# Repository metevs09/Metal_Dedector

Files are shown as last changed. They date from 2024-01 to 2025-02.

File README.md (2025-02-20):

# Metal Detector Project

This project provides a comprehensive reference for building a pulse induction metal detector. It includes the general system scheme, hardware design files, PCB designs, CAM files for manufacturing, and a USB to UART module for ESP32 integration.

Metal Detector

## Overview
The Metal Detector project is designed to help enthusiasts and professionals understand and implement a pulse induction metal detector. The repository contains:

- General Scheme: Detailed system and hardware schematics.
- PCB Design Files: Ready-to-use designs for fabricating the circuit board.
- CAM Files: Files required for computer-aided manufacturing.
- ESP32 Integration: A USB to UART module for connecting the detector to an ESP32 microcontroller.
## Features
- Pulse Induction Operation: Implements the principles of pulse induction metal detection.
- Detailed Schematics: Complete general and hardware design documents.
- PCB and CAM Files: Design files for PCB manufacturing and assembly.
- ESP32 Interface: Provides a USB to UART bridge for interfacing with ESP32-based systems.
  
## Repository Structure
```
Metal_Dedector/
- ├── CAM file/              # CAM files for PCB manufacturing
- ├── PCB files/             # PCB design files and layouts
- ├── USB to UART for ESP32/  # Interface files for ESP32 integration
- ├── Metal Dedektör.drawio   # Schematic diagram created with draw.io
- ├── README.md              # This README file
- └── SECURITY.md            # Security policy information
```
## Getting Started

### Prerequisites

#### Electronics Knowledge:
- Basic understanding of electronics and PCB design.
#### Software Tools:
- Draw.io for viewing and editing schematics.
- PCB design software (such as Eagle or KiCad) for viewing the PCB files.
- A computer with a USB interface for using the ESP32 integration module.
### Installation
#### Clone the Repository:
```git clone https://github.com/metevs09/Metal_Dedector.git```

#### Review the Design Files:
- Open Metal Dedektör.drawio with Draw.io to view the schematic.
- Check the PCB files in the PCB files/ directory.
- Refer to the files in USB to UART for ESP32/ for ESP32 interfacing details.
#### Manufacture and Assemble:
- Use the CAM files to prepare your PCB for manufacturing.
- Assemble the components following standard electronic assembly practices.
### Usage
Once the hardware is assembled:

1. Connect the ESP32 via the USB to UART interface.
2. Use your preferred development environment to load and run firmware.
3. Test the metal detector according to the provided schematic and design guidelines.
> Note: Always follow proper safety procedures when working with electronic circuits and during the assembly process.

License
This project is licensed under the MIT License. See the LICENSE file for more details.

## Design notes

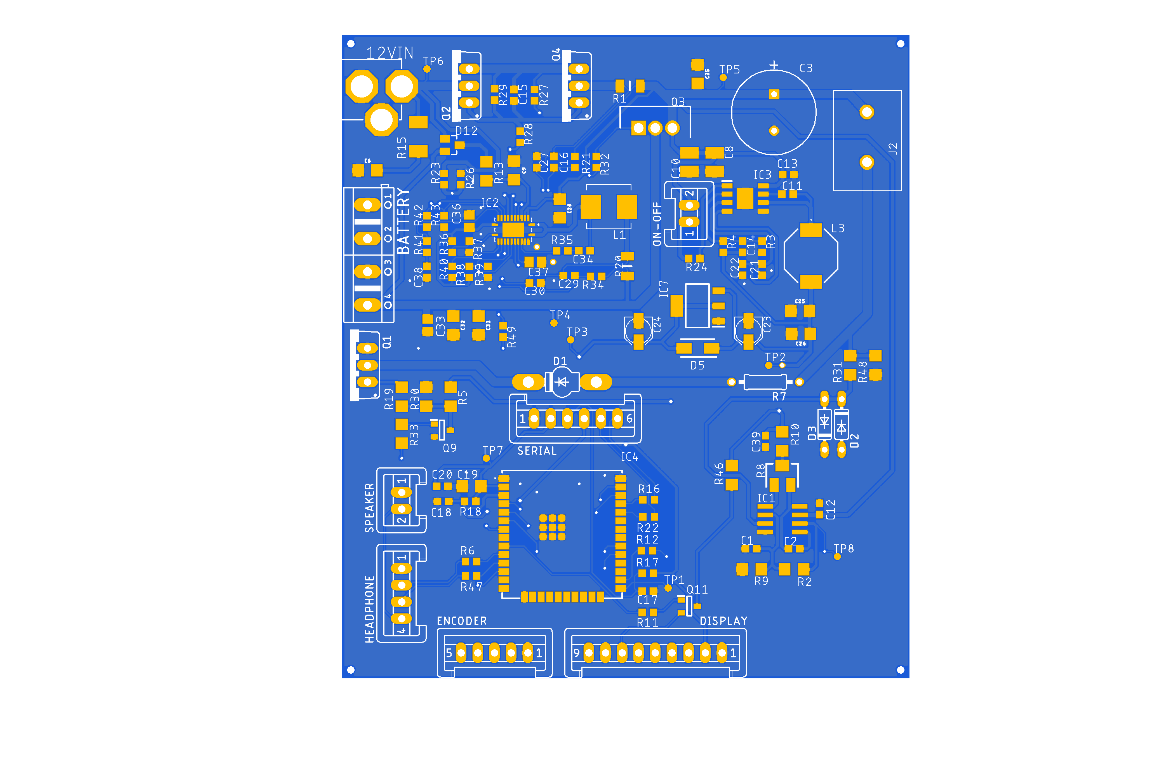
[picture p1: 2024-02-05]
CAM file/Metal Detector.png

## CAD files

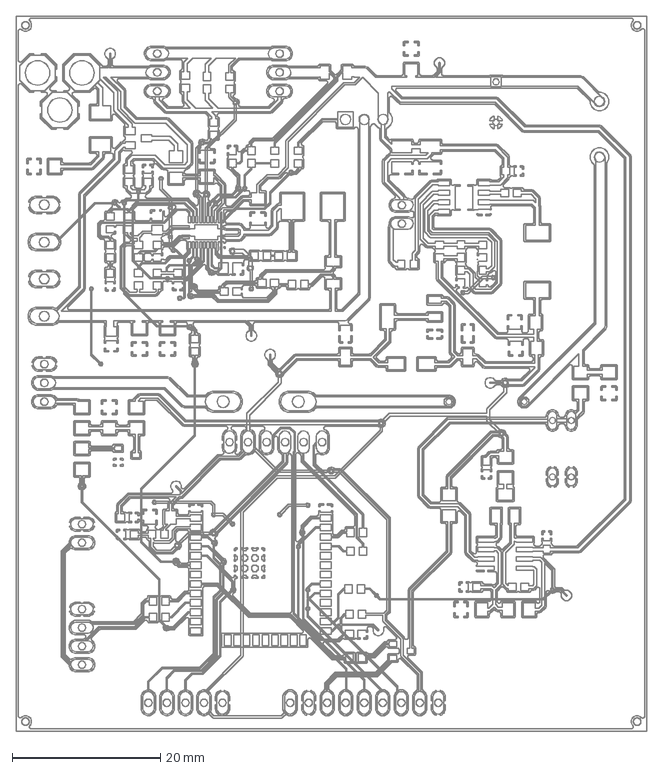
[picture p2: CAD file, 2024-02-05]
CAM file/Metal Detector.dxf
85.1 x 96.5 mm

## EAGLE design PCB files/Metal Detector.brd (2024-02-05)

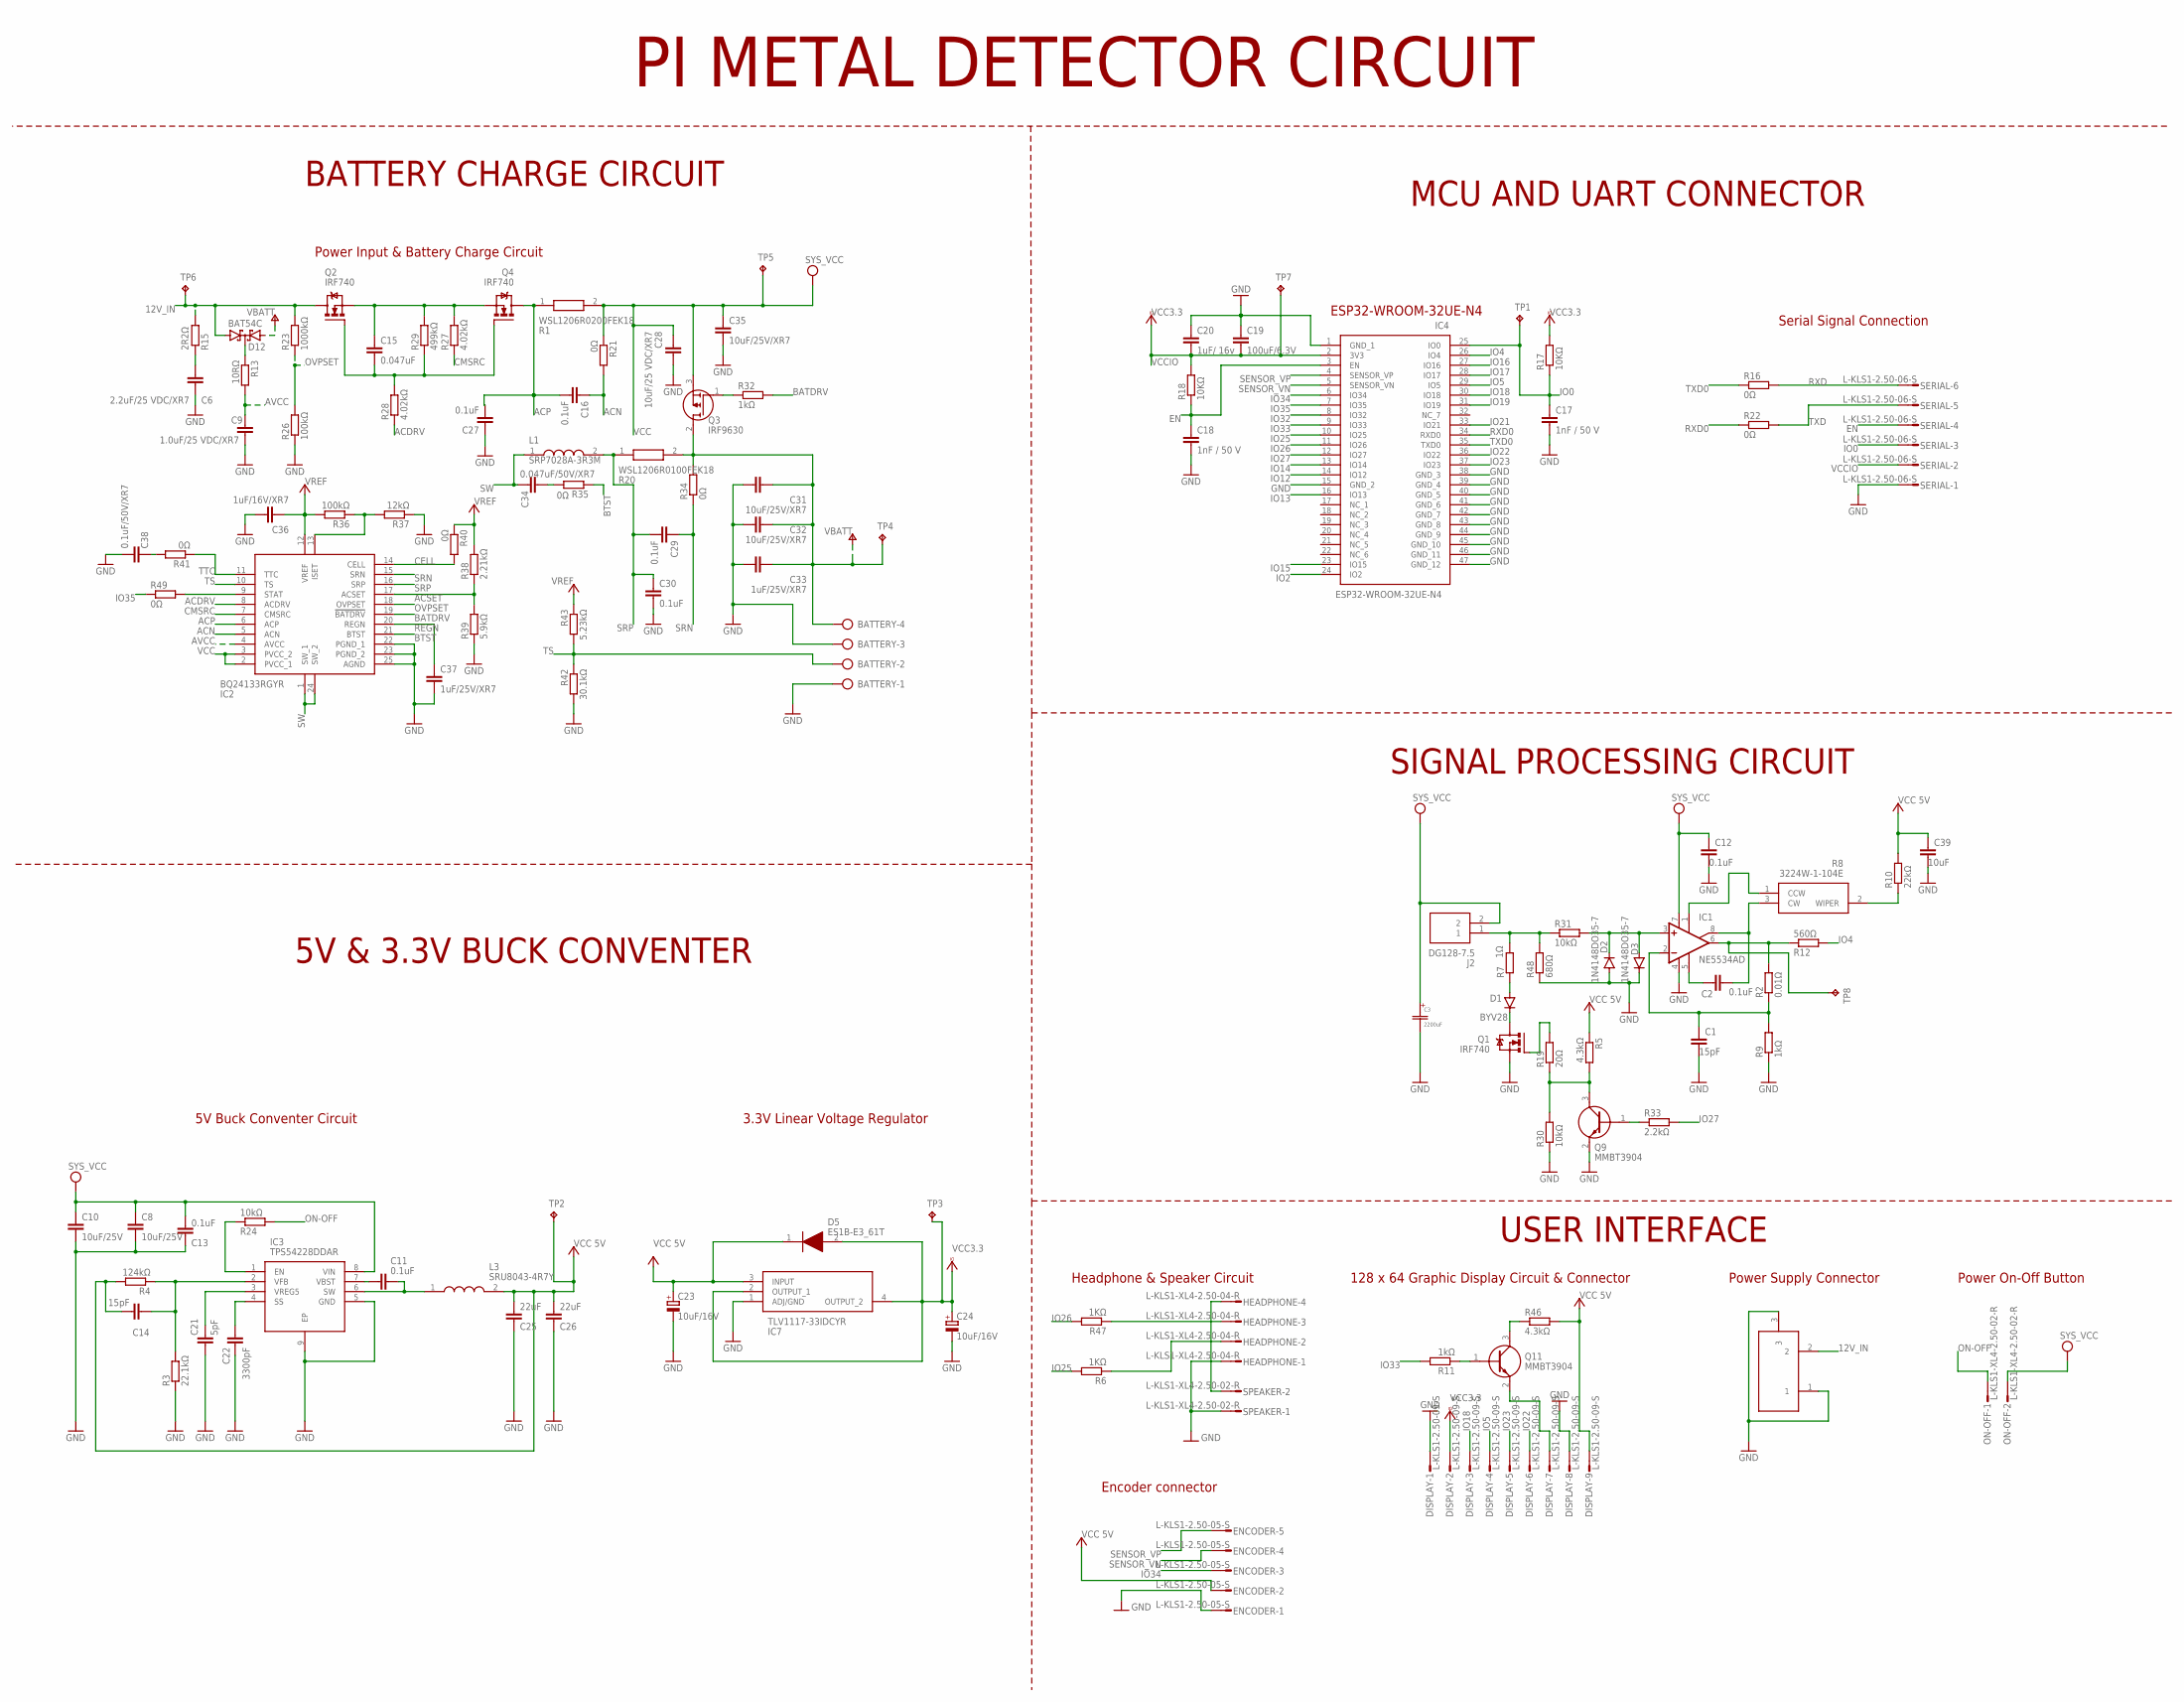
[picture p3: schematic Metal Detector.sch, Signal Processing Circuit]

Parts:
12VIN: DC21MMX; DC-21MM
BATTERY: AK500/4
C1, C14: 15pF; C0603
C2, C11, C12, C13, C16, C27, C29, C30: 0.1uF; C0603
C3: 2200uF; CAP_12.5_X_20_PAN
C6: 2.2uF/25 VDC/XR7; 1206
C8, C10: 10uF/25V; C1210
C9: 1.0uF/25 VDC/XR7; 1206
C15: 0.047uF; C0603
C17, C18: 1nF / 50 V; C0603
C19: 100uF/6.3V; C1206
C20: 1uF/ 16v; C0603
C21: 5pF; C0603
C22: 3300pF; C0603
C23, C24: 10uF/16V; PANASONIC_B
C25, C26: 22uF; 1206
C28: 10uF/25 VDC/XR7; 1206
C31, C32, C35: 10uF/25V/XR7; 1206
C33, C37: 1uF/25V/XR7; C0805
C34: 0.047uF/50V/XR7; C0603
C36: 1uF/16V/XR7; C0805
C38: 0.1uF/50V/XR7; C0603
C39: 10uF; C0603
D1: BYV28; SOD64-10
D2, D3: 1N4148DO35-7; DO35-7
D5: ES1B-E3_61T; DIOM5127X229N
D12: BAT54C; SOT23
DISPLAY: L-KLS1-2.50-09-S; S09P
ENCODER: L-KLS1-2.50-05-S; S05P
HEADPHONE: L-KLS1-XL4-2.50-04-R; S04P
IC1: NE5534AD; SO08
IC2: BQ24133RGYR
IC3: TPS54228DDAR; SOIC127P600X170-9N
IC4: ESP32-WROOM-32UE-N4; ESP32WROOM32UEN4
IC7: TLV1117-33IDCYR; SOT230P700X180-4N
J2: DG128-7.5; DG1287502P1400AH
L1: SRP7028A-3R3M; SRP7028A3R3M
L3: SRU8043-4R7Y; SRU8043330Y
ON-OFF: L-KLS1-XL4-2.50-02-R; S02P
Q1, Q2, Q4: IRF740; TO220BV
Q3: IRF9630; TO254P465X1024X2050-3P
Q9, Q11: MMBT3904; SOT95P240X120-3N
R1: WSL1206R0200FEK18; RESC3216X89N
R2: 0.01Ω; R1206
R3: 22.1kΩ; R0603
R4: 124kΩ; R0603
R5, R46: 4.3kΩ; R1206
R6, R47: 1KΩ; R0603
R7: 1Ω; 0207/10
R8: 3224W-1-104E; 3224W-1-105E
R9: 1kΩ; R1206
R10: 22kΩ; R1206
R11, R32: 1kΩ; R0603
R12: 560Ω; R0603
R13: 10RΩ; R1206
R15: 2R2Ω; R2010
R16, R21, R22, R34, R35, R40, R41, R49: 0Ω; R0603
R17, R18: 10KΩ; R0603
R19: 20Ω; R1206
R20: WSL1206R0100FEK18; RESC3216X89N
R23: 1000kΩ; R0603
R24: 10kΩ; R0603
R26, R36: 100kΩ; R0603
R27, R28: 4.02kΩ; R0603
R29: 499kΩ; R0603
R30, R31: 10kΩ; R1206
R33: 2.2kΩ; R1206
R37: 12kΩ; R0603
R38: 2.21kΩ; R0603
R39: 5.9kΩ; R0603
R42: 30.1kΩ; R0603
R43: 5.23kΩ; R0603
R48: 680Ω; R1206
SERIAL: L-KLS1-2.50-06-S; S06P
SPEAKER: L-KLS1-XL4-2.50-02-R; S02P
TP1, TP2, TP3, TP4, TP5, TP6, TP7, TP8: TPTP10R; TP10R

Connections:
12V_IN: 12VIN.2, D12.1 (A1), Q2.D, R15.2, R23.2, TP6.TP
ACDRV: IC2.8 (ACDRV), R28.1
ACN: C16.1, IC2.5 (ACN), R21.2
ACP: C16.2, C27.2, IC2.6 (ACP), Q4.D, R1.1
ACSET: IC2.17 (ACSET), R38.1, R39.2
AVCC: C9.1, IC2.4 (AVCC), R13.2
BATDRV: IC2.19 (!BATDRV), R32.2
BTST: IC2.21 (BTST), R35.1
CELL: IC2.14 (CELL), R40.2
CMSRC: IC2.7 (CMSRC), R27.1
EN: C18.1, IC4.3 (EN), R18.1, SERIAL.4
GND: 12VIN.1, 12VIN.3, BATTERY.1, BATTERY.3, C1.2, C3.2, C6.2, C8.2, C9.2, C10.2, C12.2, C13.2, C17.2, C18.2, C19.1, C20.1, C21.2, C22.2, C23.-, C24.-, C25.2, C26.2, C27.1, C28.2, C30.2, C31.2, C32.2, C33.2, C35.2, C36.1, C37.2, C38.2, C39.2, D2.A, D3.C, DISPLAY.1, DISPLAY.8, ENCODER.1, HEADPHONE.1, IC1.4 (V-), IC2.22 (PGND_1), IC2.23 (PGND_2), IC2.25 (AGND), IC3.5 (GND), IC3.9 (EP), IC4.1 (GND_1), IC4.15 (GND_2), IC4.38 (GND_3), IC4.39 (GND_4), IC4.40 (GND_5), IC4.41 (GND_6), IC4.42 (GND_7), IC4.43 (GND_8), IC4.44 (GND_9), IC4.45 (GND_10), IC4.46 (GND_11), IC4.47 (GND_12), IC7.1 (ADJ/GND), Q1.S, Q9.2 (E), R3.1, R9.1, R26.1, R30.1, R37.1, R39.1, R42.2, R48.1, SERIAL.1, SPEAKER.1
IO0: C17.1, IC4.25 (IO0), R17.1, SERIAL.3, TP1.TP
IO2: IC4.24 (IO2)
IO4: IC1.6 (OUT), IC4.26 (IO4), R2.2, R12.1, R12.2, TP8.TP
IO5: DISPLAY.4, IC4.29 (IO5)
IO12: IC4.14 (IO12)
IO13: IC4.16 (IO13)
IO14: IC4.13 (IO14)
IO15: IC4.23 (IO15)
IO16: IC4.27 (IO16)
IO17: IC4.28 (IO17)
IO18: DISPLAY.3, IC4.30 (IO18)
IO19: IC4.31 (IO19)
IO21: IC4.33 (IO21)
IO22: DISPLAY.6, IC4.36 (IO22)
IO23: DISPLAY.5, IC4.37 (IO23)
IO25: IC4.10 (IO25), R6.2
IO26: IC4.11 (IO26), R47.2
IO27: IC4.12 (IO27), R33.2
IO32: IC4.8 (IO32)
IO33: IC4.9 (IO33), R11.2
IO34: ENCODER.3, IC4.6 (IO34)
IO35: IC2.9 (STAT), IC4.7 (IO35), R49.1, R49.2
ISET: IC2.13 (ISET), R36.1, R37.2
unnamed: D2.C, D3.A, IC1.3 (+IN), R31.2
unnamed: Q1.G, R19.2
unnamed: Q9.3 (C), R5.2, R19.1, R30.2
unnamed: D1.A, R7.1
unnamed: Q9.1 (B), R33.1
unnamed: D1.C, Q1.D
unnamed: J2.1, R7.2, R31.1, R48.2
unnamed: HEADPHONE.2, R6.1
unnamed: IC1.1 (ON), R8.1 (CCW)
unnamed: R8.2 (WIPER), R10.1
unnamed: C2.2, IC1.8 (ON/CMP), R8.3 (CW)
unnamed: C1.1, IC1.2 (-IN), R2.1, R9.2
unnamed: C2.1, IC1.5 (CMP)
unnamed: D12.3 (CC), R13.1
unnamed: DISPLAY.7, Q11.2 (E)
unnamed: C6.1, R15.1
unnamed: IC3.1 (EN), R24.1
unnamed: C11.1, IC3.7 (VBST)
unnamed: C11.2, IC3.6 (SW), L3.1
unnamed: C15.1, Q2.S, Q4.S, R27.2, R29.2
unnamed: C15.2, Q2.G, Q4.G, R28.2, R29.1
unnamed: Q3.1 (G), R32.1
unnamed: C14.1, IC3.2 (VFB), R3.2, R4.1
unnamed: C34.2, R35.2
unnamed: C38.1, R41.2
unnamed: HEADPHONE.4, SPEAKER.2
unnamed: C21.1, IC3.3 (VREG5)
unnamed: Q11.1 (B), R11.1
unnamed: HEADPHONE.3, R47.1
unnamed: C22.1, IC3.4 (SS)
unnamed: Q11.3 (C), R46.1
ON-OFF: ON-OFF.1, R24.2
OVPSET: IC2.18 (OVPSET), R23.1, R26.2
REGN: C37.1, IC2.20 (REGN)
RXD: R16.2, SERIAL.6
RXD0: IC4.34 (RXD0), R22.1
SENSOR_VN: ENCODER.4, IC4.5 (SENSOR_VN)
SENSOR_VP: ENCODER.5, IC4.4 (SENSOR_VP)
SRN: C29.1, IC2.15 (SRN), R34.1
SRP: C29.2, C30.1, IC2.16 (SRP), L1.2, R20.1
SW: C34.1, IC2.1 (SW_1), IC2.24 (SW_2), L1.1
TS: BATTERY.2, IC2.10 (TS), R42.1, R43.2
TTC: IC2.11 (TTC), R41.1
TXD: R22.2, SERIAL.5
TXD0: IC4.35 (TXD0), R16.1
VBATT: BATTERY.4, C31.1, C32.1, C33.1, D12.2 (A2), Q3.2 (D), R20.2, R34.2, TP4.TP
VCC: C3.1, C8.1, C10.1, C12.1, C13.1, C14.2, C23.+, C25.1, C26.1, C28.1, C35.1, C36.2, C39.1, D5.1 (K), DISPLAY.9, ENCODER.2, IC1.7 (V+), IC2.2 (PVCC_1), IC2.3 (PVCC_2), IC2.12 (VREF), IC3.8 (VIN), IC7.3 (INPUT), J2.2, L3.2, ON-OFF.2, Q3.3 (S), R1.2, R4.2, R5.1, R10.2, R21.1, R36.2, R38.2, R40.1, R43.1, R46.2, TP2.TP, TP5.TP
VCCIO: C19.2, C20.2, C24.+, D5.2 (A), DISPLAY.2, IC4.2 (3V3), IC7.2 (OUTPUT_1), IC7.4 (OUTPUT_2), R17.2, R18.2, SERIAL.2, TP3.TP, TP7.TP

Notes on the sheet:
MCU AND UART CONNECTOR
ESP32-WROOM-32UE-N4
BATTERY CHARGE CIRCUIT
SIGNAL PROCESSING CIRCUIT
USER INTERFACE
Power Input & Battery Charge Circuit
Power On-Off Button
128 x 64 Graphic Display Circuit & Connector
Headphone & Speaker Circuit
5V Buck Conventer Circuit
5V & 3.3V BUCK CONVENTER
PI METAL DETECTOR CIRCUIT
Encoder connector
Serial Signal Connection
3.3V Linear Voltage Regulator
Power Supply Connector

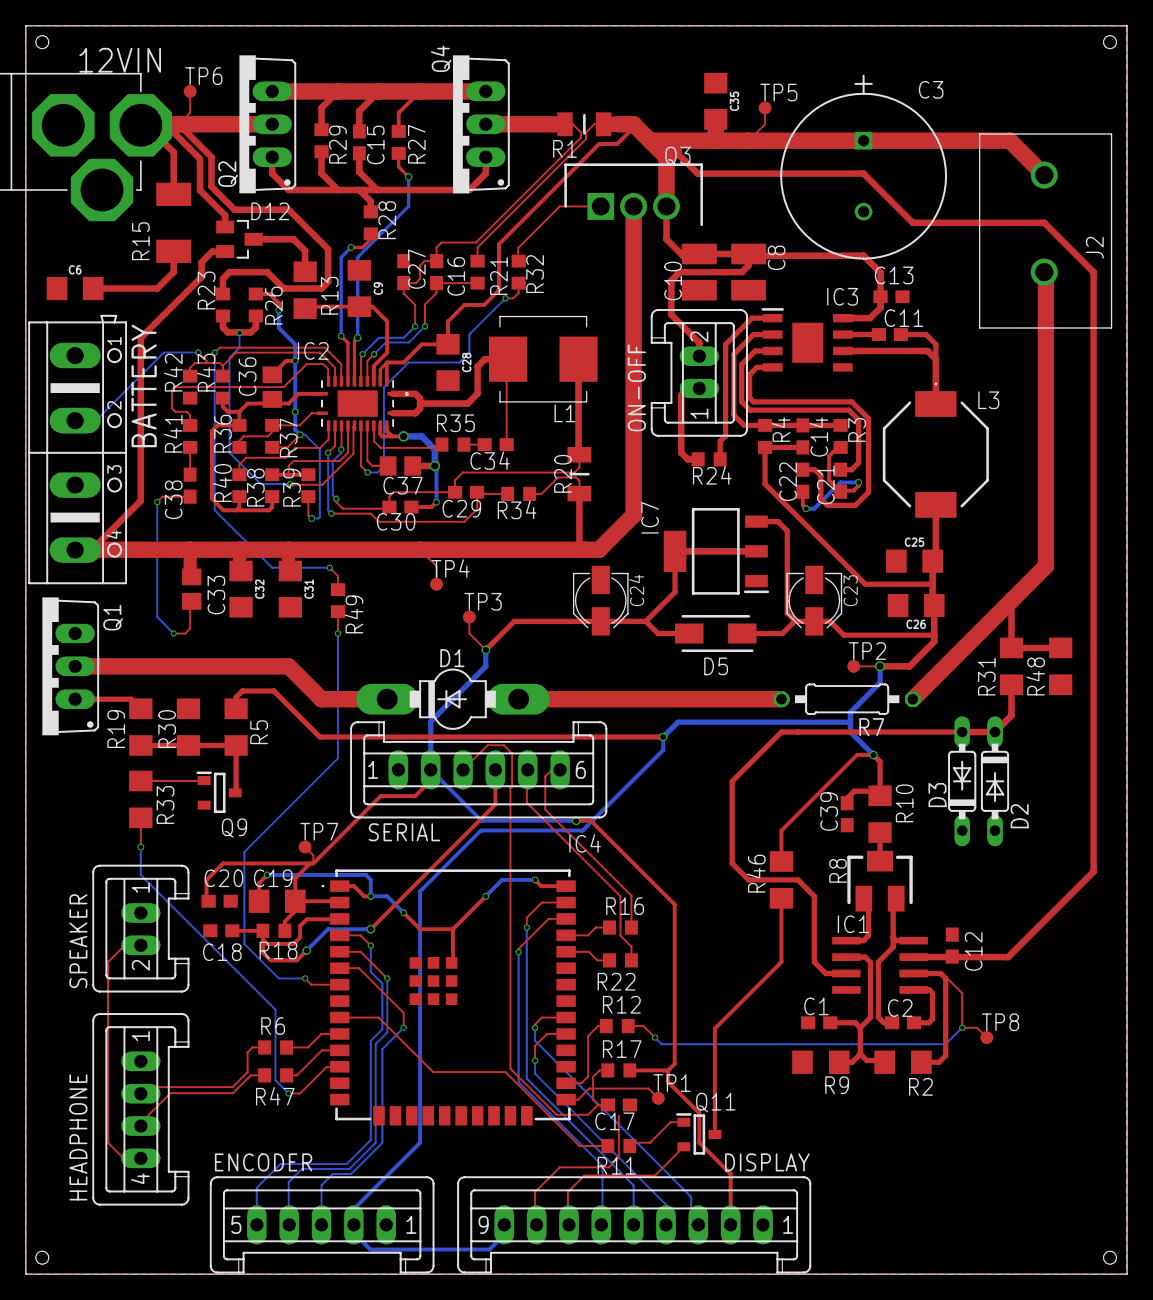
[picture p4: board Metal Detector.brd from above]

Board: 2 copper layers, 85.1 x 96.5 mm, 116 parts (0 on the bottom side), 73 nets.

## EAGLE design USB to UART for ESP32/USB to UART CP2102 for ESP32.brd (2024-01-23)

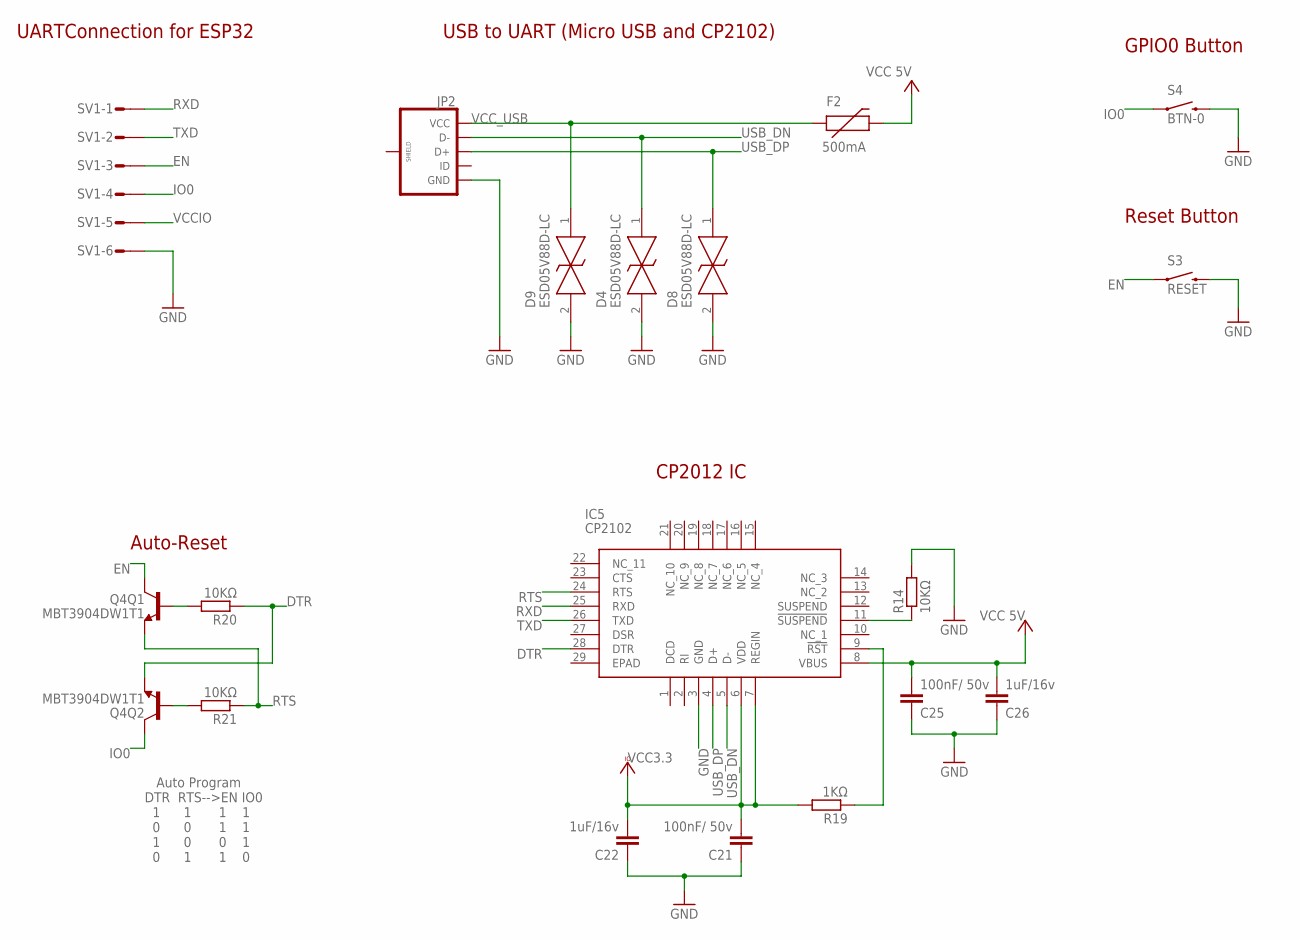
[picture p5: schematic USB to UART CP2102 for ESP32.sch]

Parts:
C21, C25: 100nF/ 50v; C0603
C22, C26: 1uF/16v; C0603
D4, D8, D9: ESD05V88D-LC; ESD05V88DLC
F2: 500mA; PTC-1206
IC5: CP2102; QFN50P500X500X100-29N
JP2: USB_MICROB_PLUGCONN-11752; USB-B-MICRO-SMD_V03
Q4: MBT3904DW1T1; SC70-6
R14, R20, R21: 10KΩ; R0603
R19: 1KΩ; R0603
S3: RESET; TACTILE_SWITCH_SMD_4.6X2.8MM
S4: BTN-0; TACTILE_SWITCH_SMD_4.6X2.8MM
SV1: L06P

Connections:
ACTıVE: IC5.11 (!SUSPEND), R14.1
DTR: IC5.28 (DTR), Q4.1 (E), R20.1
EN: Q4.3 (C), S3.1, S3.2 (1), SV1.3
GND: C21.1, C22.1, C25.1, C26.1, D4.2, D8.2, D9.2, IC5.3 (GND), JP2.GND, R14.2, S3.3 (2), S3.4 (2), S4.3 (2), S4.4 (2), SV1.6
IO0: Q4.6 (C), S4.1, S4.2 (1), SV1.4
unnamed: Q4.5 (B), R20.2
unnamed: Q4.2 (B), R21.2
unnamed: IC5.9 (!RST), R19.1
RTS: IC5.24 (RTS), Q4.4 (E), R21.1
RXD: IC5.25 (RXD), SV1.1
TXD: IC5.26 (TXD), SV1.2
USB_DN: D4.1, IC5.5 (D-), JP2.D-
USB_DP: D8.1, IC5.4 (D+), JP2.D+
VCC: C25.2, C26.2, F2.2, IC5.8 (VBUS)
VCCIO: C21.2, C22.2, IC5.6 (VDD), IC5.7 (REGIN), R19.2, SV1.5
VCC_USB: D9.1, F2.1, JP2.VBUS (VCC)

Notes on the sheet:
GPIO0 Button
Reset Button
Auto-Reset
Auto Program DTR RTS-->EN IO0 1 1 1 1 0 0 1 1 1 0 0 1 0 1 1 0
USB to UART (Micro USB and CP2102)
UARTConnection for ESP32
CP2012 IC

Board: 2 copper layers, 18 parts (0 on the bottom side), 16 nets, no tracks yet.

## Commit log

2023-12-23 Metal Detector PCB
    Still designing Signal Processing Circuit
    [Metal Detector.sch]
2023-12-23 Add files via upload
    Still designing signal processing circuit
    [Metal Detector.sch]
2023-12-25 Add files via upload
    Adding MCU sheet
    [Metal Detector.sch]
2023-12-27 Add files via upload
    Adding MCU peripherals, still designin MCU parts
    [Metal Detector.sch]
2023-12-27 Add files via upload
    Completed designing MCU and Peripheral sheet
    [Metal Detector.sch]
2023-12-27 Add files via upload
    Adding Subtitle to sheet
    [Metal Detector.sch]
2023-12-28 Add files via upload
    Deleted sheet 2 and include content to sheet 1 for software limitations after that edited sheet 1
    [Metal Detector.sch]
2023-12-28 Add files via upload
    Added Battery charging & power regulator and User Interface components, created board file.
    Design process still on progress.
    [Metal Detector.brd, Metal Detector.sch]
2023-12-29 Add files via upload
    Design process still on progress
    [Metal Detector.brd, Metal Detector.sch]
2023-12-31 Add files via upload
    Still designin power circuit but should be change battery charge IC for tehnical limitation
    [Metal Detector.brd, Metal Detector.sch]
2024-01-01 Add files via upload
    Adding Voltage Regulator Circuits
    [Metal Detector.brd, Metal Detector.sch]
2024-01-01 Add files via upload
    Still designing battery charger and power line managment circuit
    [Metal Detector.brd, Metal Detector.sch]
2024-01-02 Add files via upload
    Still designing battery charge circuit, it is almost over.
    [Metal Detector.brd, Metal Detector.sch]
2024-01-03 Add files via upload
    Battery Charge Circuit design process is finished but This design is unexpectedly expencive due to peripheral components.
    Founded new IC and will change design for new IC. ( I'm so sorry for that : /) will be more cost effective.
    [Metal Detector.brd, Metal Detector.sch]
2024-01-04 Add files via upload
    Assigned ISET adn ACSET value for selected battery
    [Metal Detector.brd, Metal Detector.sch]
2024-01-05 Add files via upload
    Added LCD connections
    [Metal Detector.brd, Metal Detector.sch]
2024-01-05 Add files via upload
    adding speaker's control circuit (Design process still in progress)
    [Metal Detector.brd, Metal Detector.sch]
2024-01-06 Add files via upload
    Connected and added Spekers, volume and sensitivty connections with MCU
    [Metal Detector.brd, Metal Detector.sch]
2024-01-09 Add files via upload
    Redesigned signal processing circuit due to ground layer
    [Metal Detector.brd, Metal Detector.sch]
2024-01-10 Add files via upload
    Fixed sum bug
    [Metal Detector.brd, Metal Detector.sch]
2024-01-13 Add files via upload
    Redesigned Regulators Circuit and editing sheet
    [Metal Detector.brd, Metal Detector.sch]
2024-01-15 Add files via upload
    Redesigned Uaer Interface Block for Encoder (Encoder will include other design step)
    [Metal Detector.brd, Metal Detector.sch]
2024-01-16 Add files via upload
    Add connector to User Interface
    [Metal Detector.brd, Metal Detector.sch]
2024-01-19 Add files via upload
    Separated USB to UART part edited User interface and Redesign Buck conventer Circuit for Implementation problem : /
    [Metal Detector.brd, Metal Detector.sch]
2024-01-19 Add files via upload
    Designed buck conventer and linear voltage regulator circuit and simulated circuit on TI platform next progress change opamp for offset voltage implementation issue and redesign headphone connection after that All design will on last checking process before drawing layout
    [Metal Detector.brd, Metal Detector.sch]
2024-01-23 Add files via upload
    Desing process is done, USB to UART brigdge is separated from board, after last power and battery circuit check will get next section
    ,the next section is PCB board design that is the last steps
    [Metal Detector.brd, Metal Detector.sch]
2024-01-23 Create USB to UART bridge for ESP32
2024-01-23 USB to UART for ESP32
    [USB to UART CP2102 for ESP32.brd, USB to UART CP2102 for ESP32.sch]
2024-01-23 Add files via upload
    Included USB to UART for ESP32 files
    [USB to UART CP2102 for ESP32.brd, USB to UART CP2102 for ESP32.sch]
2024-01-23 Add files via upload
    Changed some resistor value for set electrical input parameter on Battery charge IC
2024-01-24 Add files via upload
    Started design PCB layout first start from battery charge circut, still desing process
    [Metal Detector.brd, Metal Detector.sch]
2024-01-25 Add files via upload
    Battery charge circuit on design progress
    [Metal Detector.brd, Metal Detector.sch]
2024-01-26 Add files via upload
    Designed Battery charge circut next design power circut and connection two circuit
    [Metal Detector.brd]
2024-01-26 Add files via upload
    Removed all component ot board
    [Metal Detector.brd, Metal Detector.sch]
2024-01-28 Add files via upload
    Optimizated PCB trace and designed 12V to 5V Buck coneventer
    [Metal Detector.brd, Metal Detector.sch]
2024-01-29 Add files via upload
    Redesign 5V buck conventer circuit for implementation problem
    [Metal Detector.brd, Metal Detector.sch]
2024-01-29 Add files via upload
    Designed 5V, 3.3V power circuit and signal processing circuit after that repositioned component I will do microprossesor connection and repositioning on next section
    [Metal Detector.brd, Metal Detector.sch]
2024-01-30 Add files via upload
    All schematic and board design process is done after that upload BOM file, 3rd view docs and manufacturing files
    [Metal Detector.brd, Metal Detector.sch]
2024-02-01 Gerber Files
    [copper_bottom.gbr, copper_top.gbr, gerber_job.gbrjob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]
2024-02-01 Create drill
2024-02-01 Create assembly
2024-02-05 Add files via upload
    Edited pcb trace nad add test point
    [Metal Detector.brd, Metal Detector.sch]
2024-02-05 Add files via upload
    Edited pcb layout and removed some via from gnd
    [Metal Detector.dxf]
2024-02-05 Add files via upload
    Remove some via and edited pcb trace
    [Metal Detector.brd]

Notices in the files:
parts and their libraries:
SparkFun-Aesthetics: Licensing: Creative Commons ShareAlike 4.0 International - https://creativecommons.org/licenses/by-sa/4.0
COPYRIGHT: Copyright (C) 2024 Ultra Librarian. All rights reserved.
